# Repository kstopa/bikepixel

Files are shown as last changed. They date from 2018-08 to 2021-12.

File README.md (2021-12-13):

# Bike Pixels

Open Source Hardware project to build a set of highly customizable bycicle lights based on Arduino and Neo Pixel RGB matrixes. Currently all models can present different images in different colors with custom effects (blinking, bitting) and with adjustable brightness.

Check [Bike Pixel Official site](https://bikepixels.com) to the more details and recent news.

## Required software
All required applications to edit and design the different Bike Pixel models are open source. Bellow you can find all the tools that were used to design Bike Pixels:

* [Arduino IDE](https://www.arduino.cc/en/Main/Software): to write, biuld and upload the code to the Arduino board.
* [FreeCAD](https://www.freecadweb.org/wiki/Download): to design the cases.
* [KiCAD](http://kicad.org/download/): to design electronic schemas and the PCBs.
* [Fritzing](https://fritzing.org): only for circuit sketch documentation.

## Bike Pixel L (or rear)

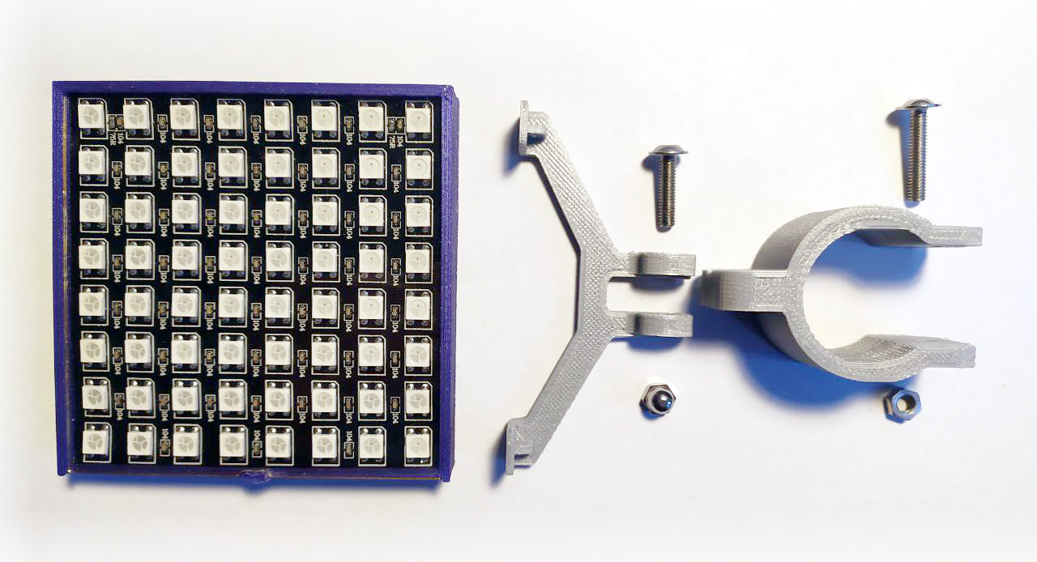
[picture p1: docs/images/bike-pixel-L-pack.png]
Bike Pixel L parts Bike Pixel L Parts


This model it is intended to be installed in the back part of the bike like the saddle or over bike structure. Main properties and parts:

* Preset 10 diferent icons
* Adjustable color and brightness
* 64 LEDs NeoPixel matrix
* 84 x 84 x 14 mm (3.3 x 3.3 x 0.55 in)

### Components

To build your own Bike Pixel L you should have all the elements listed on this bill of materials:

* 1 x Arduino Pro Mini or Nano;
* 1 x NeoPixel 8x8 matrix (80x80x2mm);
* 3 x 10 kΩ resistence;
* 1 x 470 Ω resistence;
* 2 x 22 kΩ resistor;
* 1 x 1000 uf/6.3V capacitator (recommended but optional);
* 3 x vertical touch switches;
* 1 x on\off botton (optional if your battery holder have one built-in);
* 1 x TP4056 module;
* 1 x 5V Step-up module;
* 1 x >2000 mAh LiPo battery;
* 1 x M3 30mm bolt;
* 1 x M3 20mm bolt; 
* 2 x M3 nuts;
* connection PCB;
* wires and soldering stuff;
* 3D printed case;
* 3D printed holder.

More details on each part are commented on following points. Links to different proviedars and prices can be found on this blog entry.

### Case

The case is divided in multiple parts designed to be 3D printed. Current designs include body and holder models.

#### Main body

The body is composed the main body and a cover. You can print them using PLA altought for the cover a 1 mm thick piece of plexi is recommended.

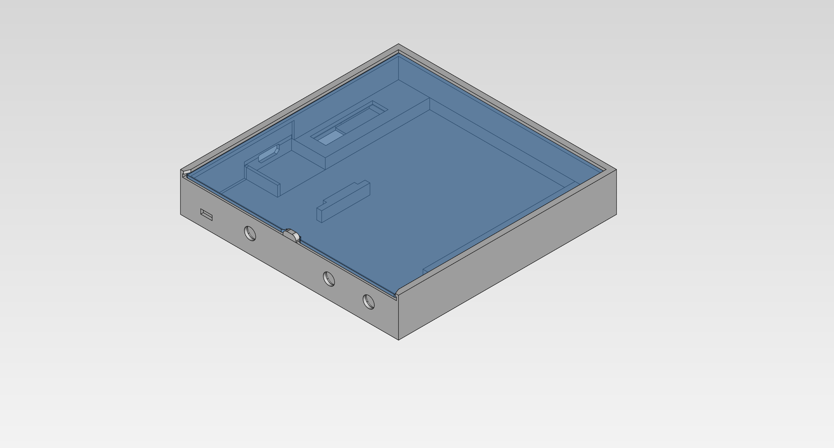
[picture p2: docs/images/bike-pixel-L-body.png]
Bike Pixel L body with cover Bike Pixel L body


You can get production files bellow.

| Part | Files |  
|---|---|
| Body | [sld](rear/case/body/case_bikepixels_rear.stl) |
| Cover| [sld](rear/case/cover/case_bikepixels_rear_cover.stl), [svg](rear/case/cover/case_bikepixels_rear_cover.svg), [pdf](rear/case/cover/case_bikepixels_rear_cover.pdf) |

#### Bike attachment 

Current holder design is divided into two pieces. An attachment and a hook. To mount them on a bycicle you will need 2 x M3 nuts and 2 x M3 bolts of 30 and 20mm in lenght.

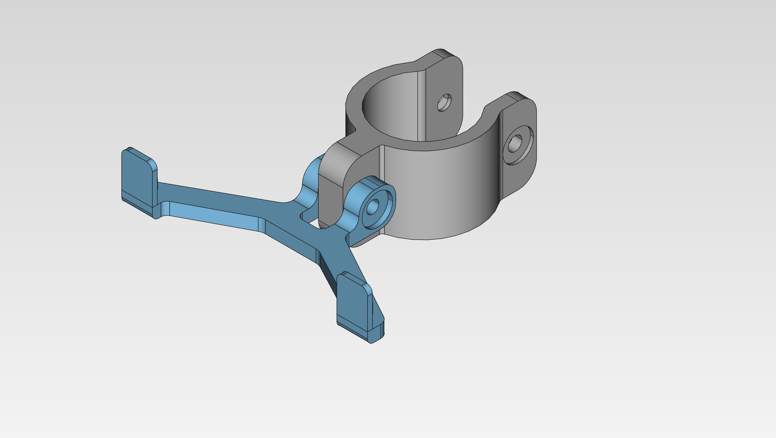
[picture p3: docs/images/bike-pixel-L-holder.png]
Bike Pixel L holder


You can get production files bellow.

|  Part | Files |
|---|---|
| Hook | [sld](rear/case/holder/holder_base_28mm-holder_hook.stl) |
| Attachment | [sld](rear/case/holder/holder_base_28mm-holder_attach.stl)  |

### Electronics

#### Main components

To build your L model you will need all the electronic parts listed bellow along with some additional requirements.

| Part | Comment |
|---|---|
| Arduino Nano or Pro Mini | Clone or original |
| USB C TP4056 charging module | More information on [this blog entry](https://bikepixels.com/2019/11/10/how-to-add-a-lipo-battery-in-our-arduino-projects/) |
| 5V Step-up module | Any module designed for LiPo batteries |
| NeoPixel 8x8 RGB matrix | Flexible 80x80x2mm model |
| >2000 LiPo battery | Max. 4 mm thicknes |

#### Conexions PCB

The PCB encapsulates the switches and manage connections between the Arduino board, the step-up module and the RGB matrix. All the design have been created with KiCAD. All the source files including schematinc, netlist and PCB board are availble [here](./rear/electronics/bikepixel rear/).

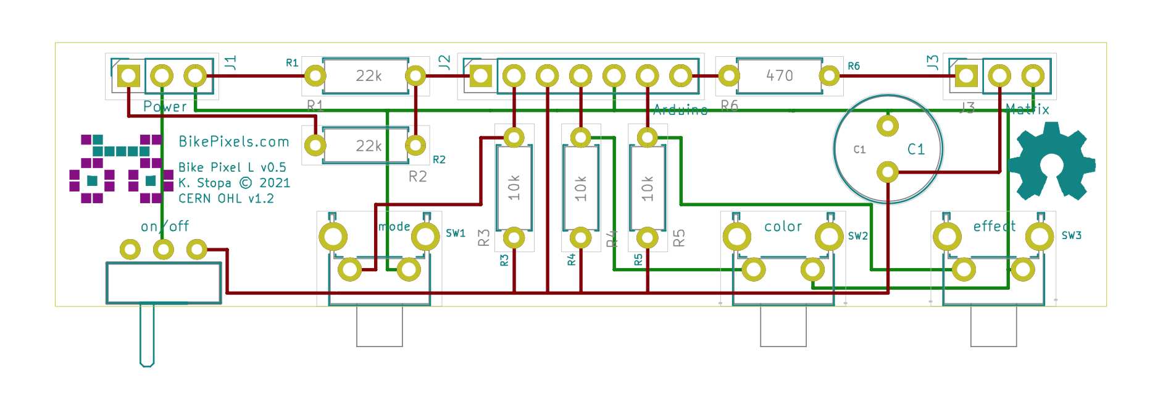
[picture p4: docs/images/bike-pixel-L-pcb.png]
Bike Pixel L PCB


Production files are available in different formats and are linked bellow:

|                         Format                           |
|----------------------------------------------------------|
| [gerber](rear/electronics/production files/gerber)       |
| [pdf](rear/electronics/production files/pdf)             |
| [svg](rear/electronics/production files/svg)             |

#### Assambley

To connect evrything together please follow schema bellow. After soldering everthing you can proceed to upload the code to Arduino.

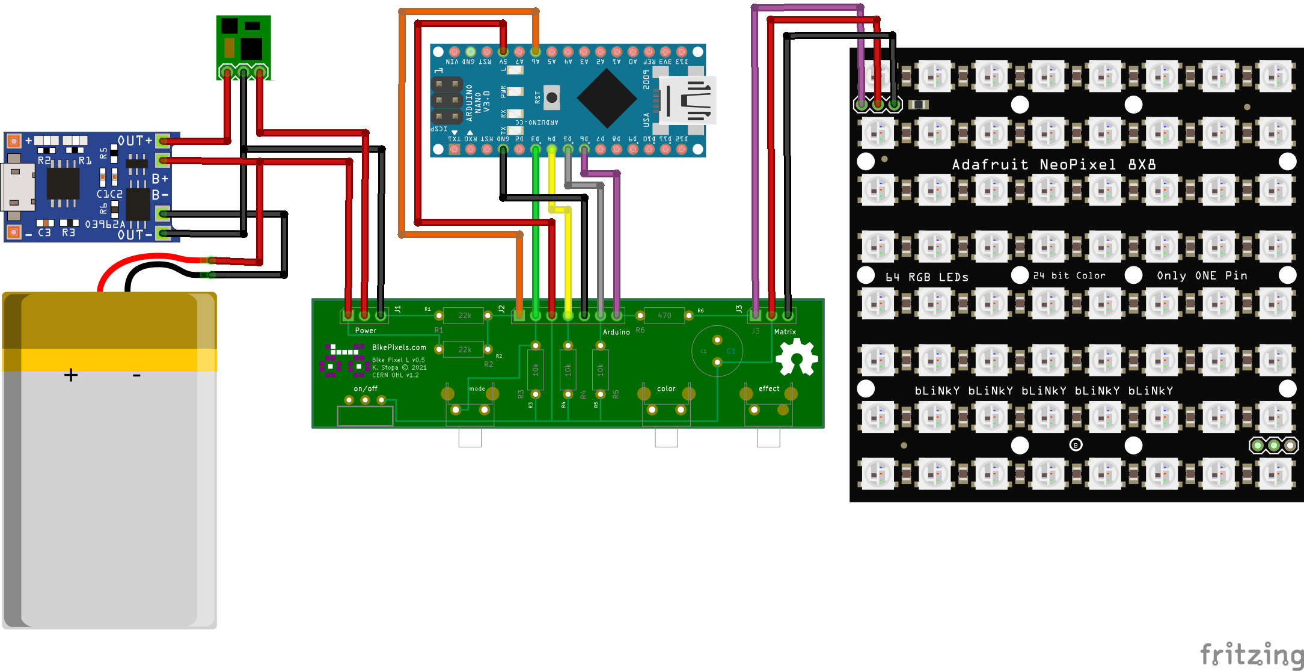
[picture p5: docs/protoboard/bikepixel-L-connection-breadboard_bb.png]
Bike Pixel L connection BikePixel PCB conection


## Code 

To compile the BikePixel [code for Arduino](./rear/src/bikepixel_sketch.ino), you'll need some extra libraries:

* [Adafruit GFX](https://github.com/adafruit/Adafruit-GFX-Library)
* [Adafruit NeoPixel](https://github.com/adafruit/Adafruit_NeoPixel)
* [Adafruit NeoMatrix](https://github.com/adafruit/Adafruit_NeoMatrix)

Note that you can install these libraries directly from Arduino Studio (Sketch menu, > Include Library > Manage Libraries) or by placing it after download into the Arduino Library folder (usally in your home).

## Certification

Bike Pixel is certified by the Open Source Hardware Association ([OSHWA](https://en.wikipedia.org/wiki/Open_Source_Hardware_Association)). 
OSWHA is a non-profit organization that advocates for open-source hardware focusing on promotion, education and comertialization of open 
products. OSHWA also manages certification program for open-source hardware that indicate that given product meet standard criteria for 
open-source compliance. Current Bike Pixel version has certificate number [PL000007](https://certification.oshwa.org/pl000007.html).

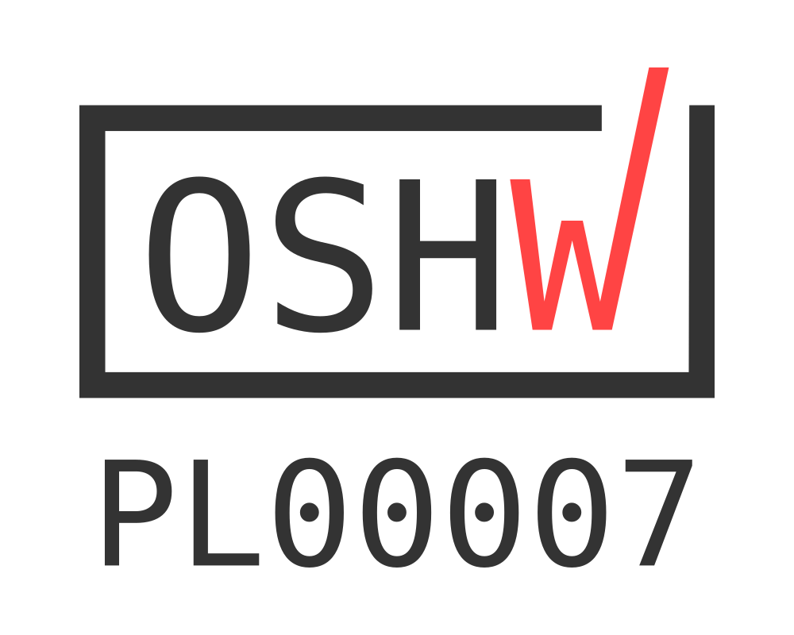
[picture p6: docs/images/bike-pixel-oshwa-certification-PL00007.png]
Bike Pixels OSHWA certificate PL000007 Bike Pixels OSHWA certificate


## License

As the project is compond by software, hardware and documentation each of these parts are licensed under the terms of specific license.

### Software License

Copyright © 2021 by BikePixels.com and contributors:

* Krzysztof Stopa ([kstopa](https://github.com/kstopa/)).

Bike Pixels contains free software: you can redistribute it and/or modify it under the terms of the GNU General Public License as published by the Free Software Foundation, either version 3 of the License, or any later version.

Bike Pixels is distributed in the hope that it will be useful, but WITHOUT ANY WARRANTY; without even the implied warranty of MERCHANTABILITY or FITNESS FOR A PARTICULAR PURPOSE. See the GNU Lesser General Public License for more details.

You should have received a copy of the GNU Lesser General Public License along with CAMS tools. If not, see http://www.gnu.org/licenses/.

### Hardware License

Copyright © 2021 by BikePixels.com and contributors:

* Krzysztof Stopa ([kstopa](https://github.com/kstopa/)).

Hardware elements is licensed under the CERN OHL v. 1.2.

You may redistribute and modify this documentation under the terms of the CERN OHL v.1.2. (http://ohwr.org/cernohl). This documentation is distributed WITHOUT ANY EXPRESS OR IMPLIED WARRANTY, INCLUDING OF MERCHANTABILITY, SATISFACTORY QUALITY AND FITNESS FOR A PARTICULAR PURPOSE. Please see the CERN OHL v.1.2 for applicable conditions.

### Documentation and images License

Copyright © 2021 by BikePixels.com and contributors:

* Krzysztof Stopa ([kstopa](https://github.com/kstopa/)).

Documentation and image files are distributed under the Attribution-ShareAlike 4.0 International (CC BY-SA 4.0) lisence. The full text of the license can be found at the [CC BY-SA 4.0 page](https://creativecommons.org/licenses/by-sa/4.0/legalcode).

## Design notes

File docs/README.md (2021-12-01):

# Content

## Custom parts

Contains all custom parts used on KiCad and Fritzing used to design Bike Pixels Front and
Rear cirquits and PCBs.

## Protoboard

Contains proto board simple design used for design and debugging.

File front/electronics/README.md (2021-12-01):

This folder contains:
 * custom components: i.e. parts and graphinc elements that compuds the PCB design.
 * production files: to be send in `gerber` and `svg` formats that  can be directly send to a PCB manufacturer.

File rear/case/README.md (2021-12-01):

# Content

This folder conaint all the needed files to print a Bike Pixel L (or rear) case

* body: FreeCAD file and production stl with the case main body.
* cover: FreeCAD file and production stl, pdf and svg files with the body cover (as can be printed or cut on plexy).
* holder: FreeCAD file and production of a holder to attach the body to the bike for different sizes. Includes production files for the bike attachment and a hook parts.

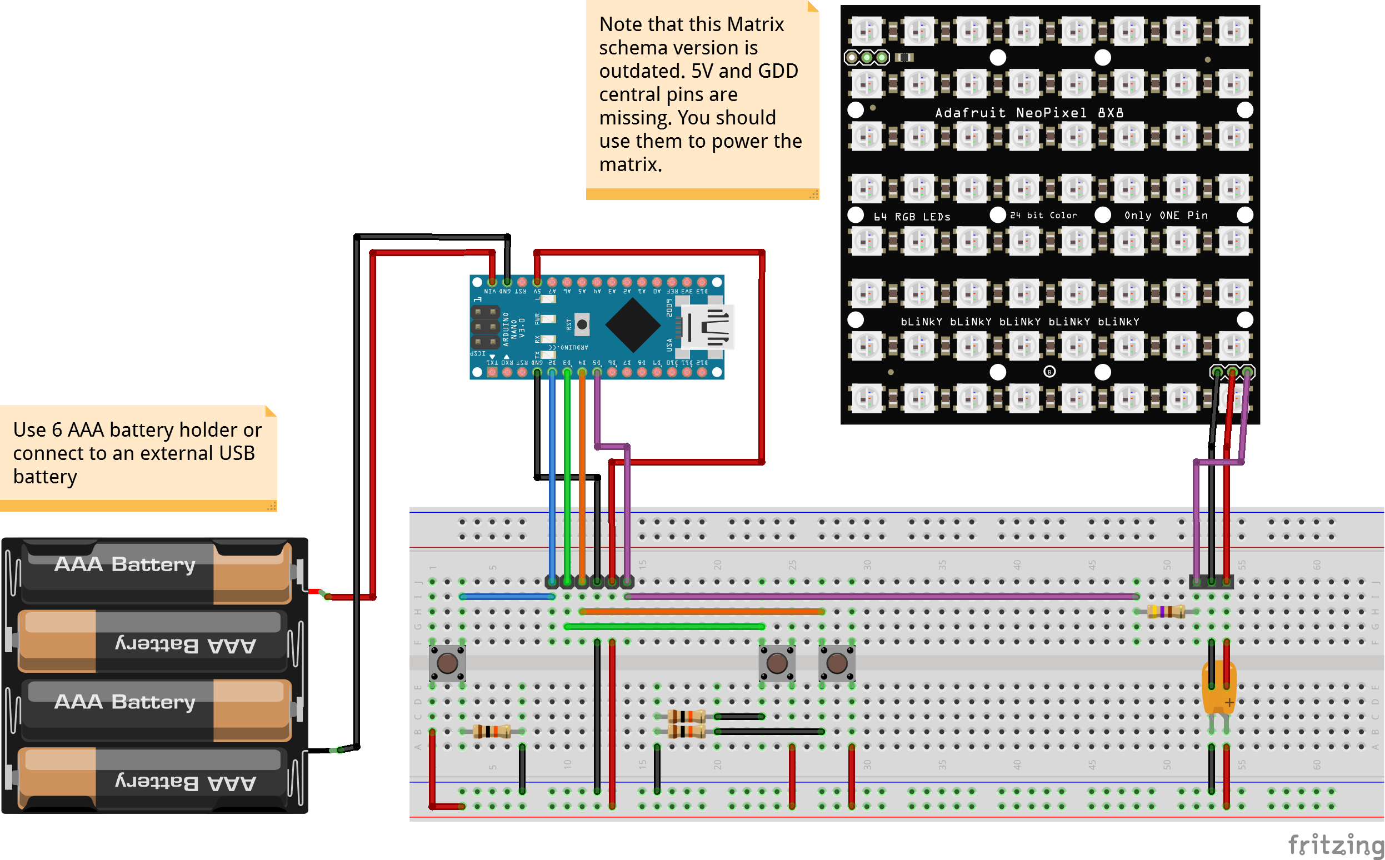
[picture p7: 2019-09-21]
rear/electronics/sketch protoboard.png

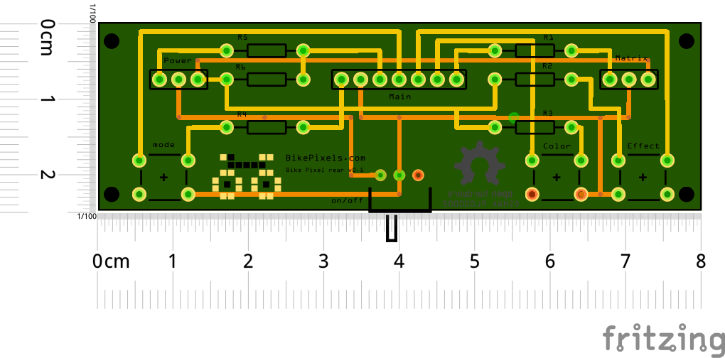
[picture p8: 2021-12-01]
rear/electronics/sketch pcb.png

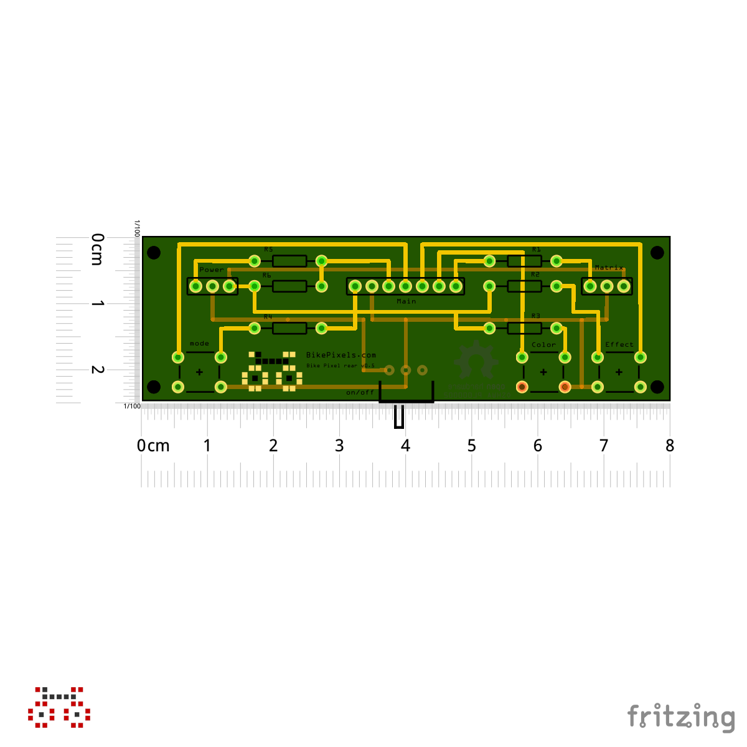
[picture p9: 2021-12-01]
rear/electronics/sketch pcb_pcb.png

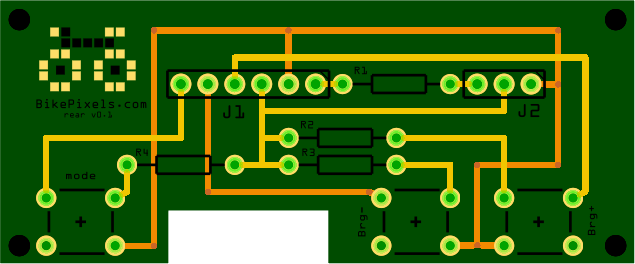
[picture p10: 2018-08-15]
docs/protoboard/sketch pcb.png

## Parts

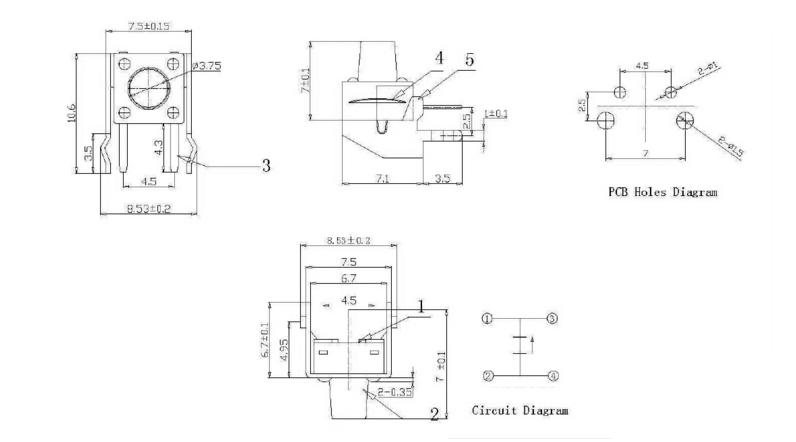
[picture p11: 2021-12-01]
front/electronics/custom components/pushbutton_vertical_sketch.jpg

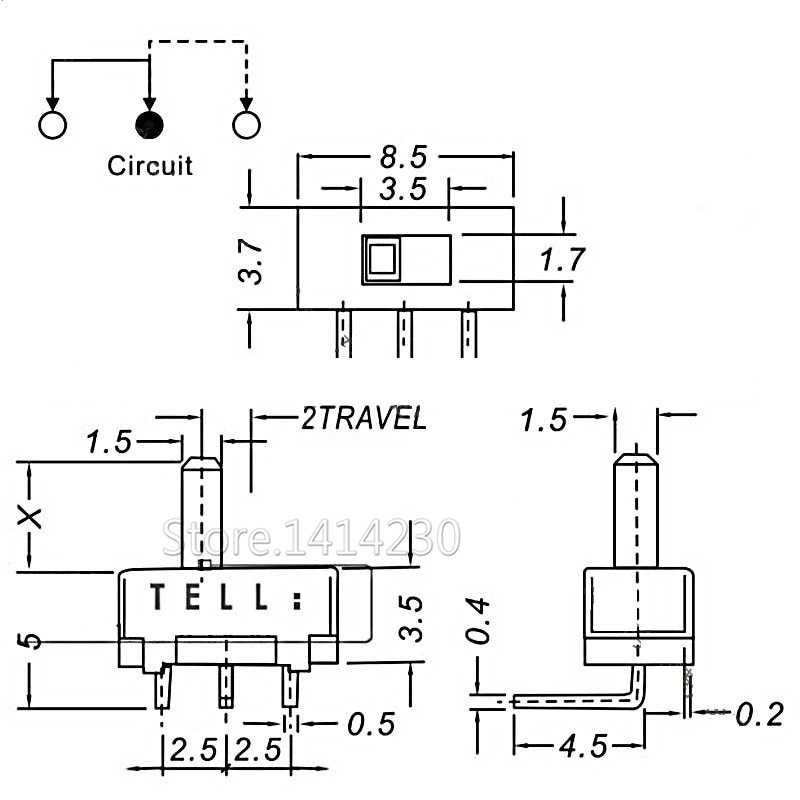
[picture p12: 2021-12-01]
front/electronics/custom components/fritzing_onoff_slide_switch on-off-mini-SS12D00-SS12D03G5-3pin.jpg

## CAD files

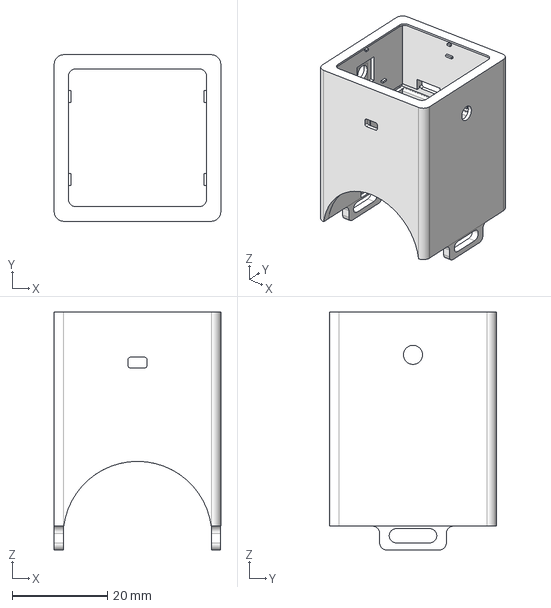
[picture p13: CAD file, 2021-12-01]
front/case/bikepixel_front_45.FCStd
35.0 x 35.0 x 50.0 mm

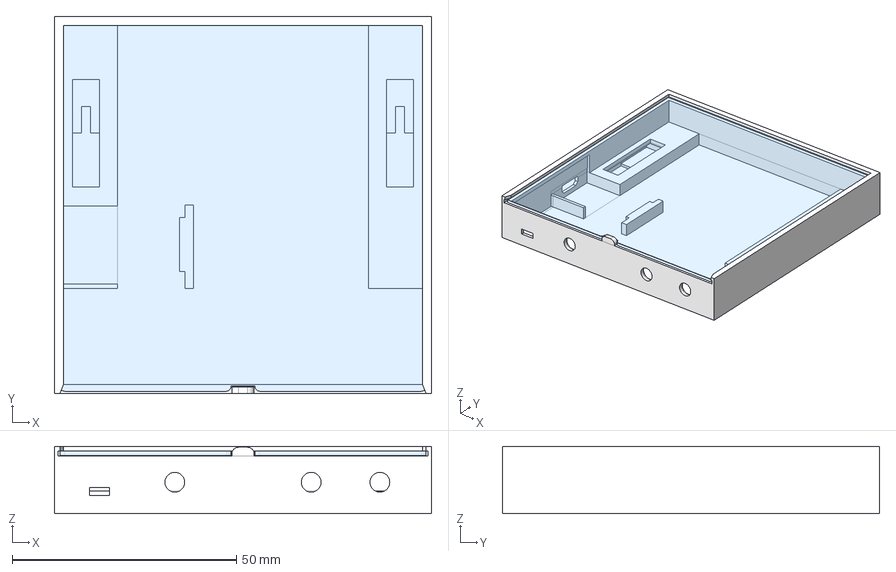
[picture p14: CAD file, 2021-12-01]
rear/case/body/case_bikepixels_rear.FCStd
84.0 x 84.0 x 15.0 mm
Case body
Case cover

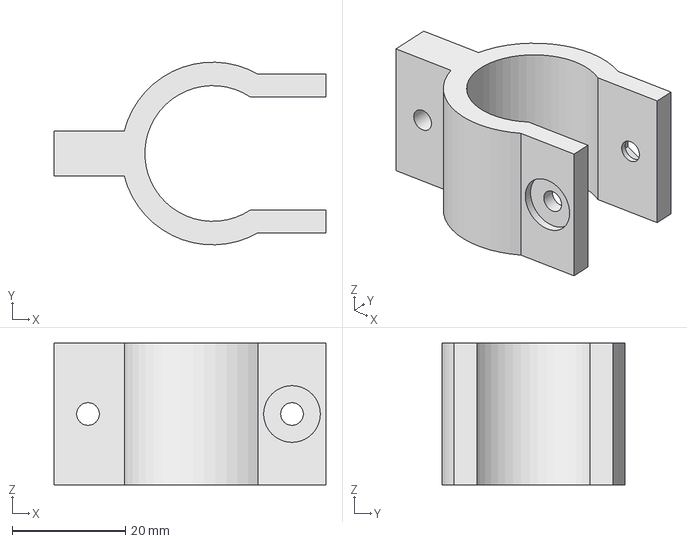
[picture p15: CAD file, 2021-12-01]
rear/case/holder/holder_base_24mm.FCStd
48.0 x 32.2 x 25.0 mm

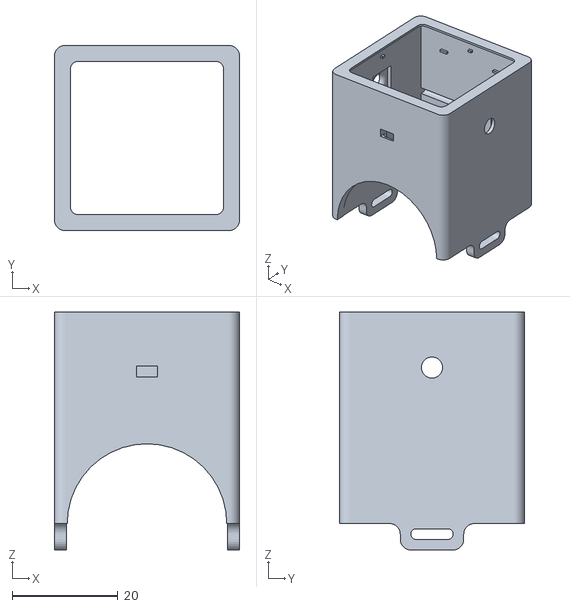
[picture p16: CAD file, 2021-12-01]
front/case/bike_pixel_front_v0.stl
35.0 x 35.0 x 45.0

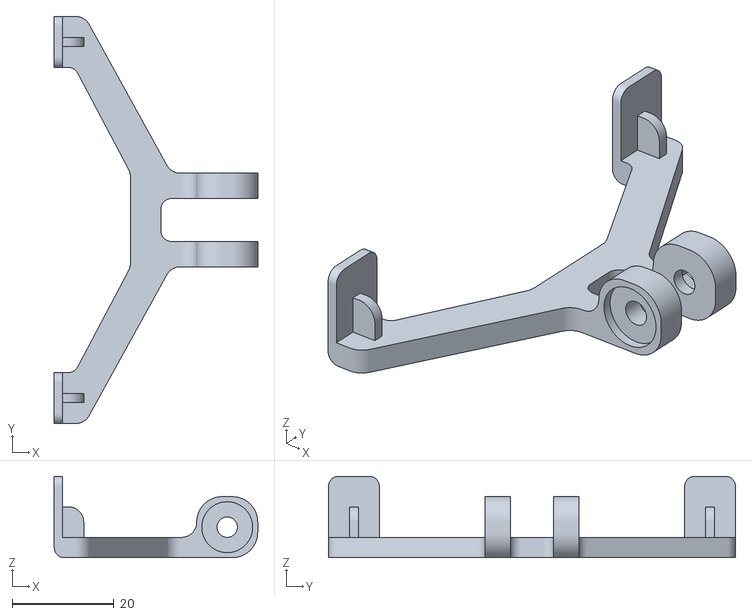
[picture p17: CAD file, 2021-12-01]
rear/case/holder/holder_base_28mm-holder_hook.stl
40.0 x 80.0 x 16.0

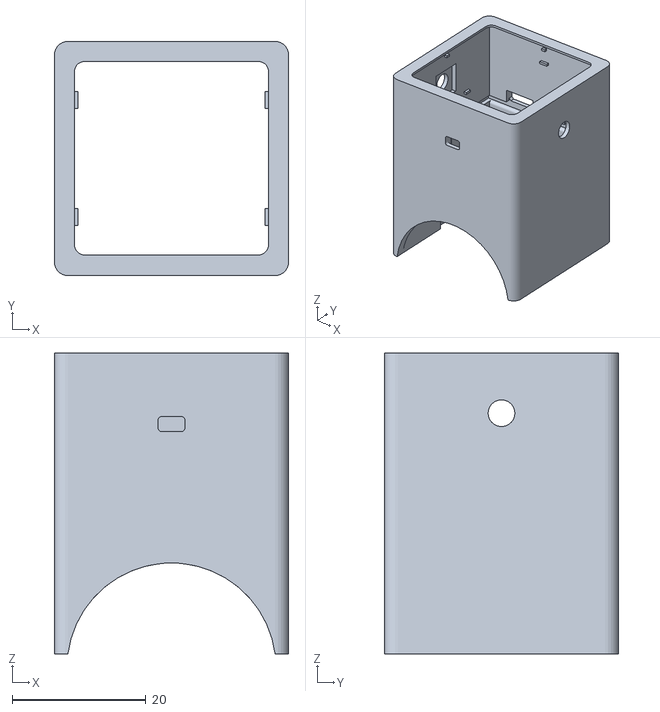
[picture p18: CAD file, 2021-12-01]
front/case/bike_pixels_front.stl
35.0 x 35.0 x 45.0

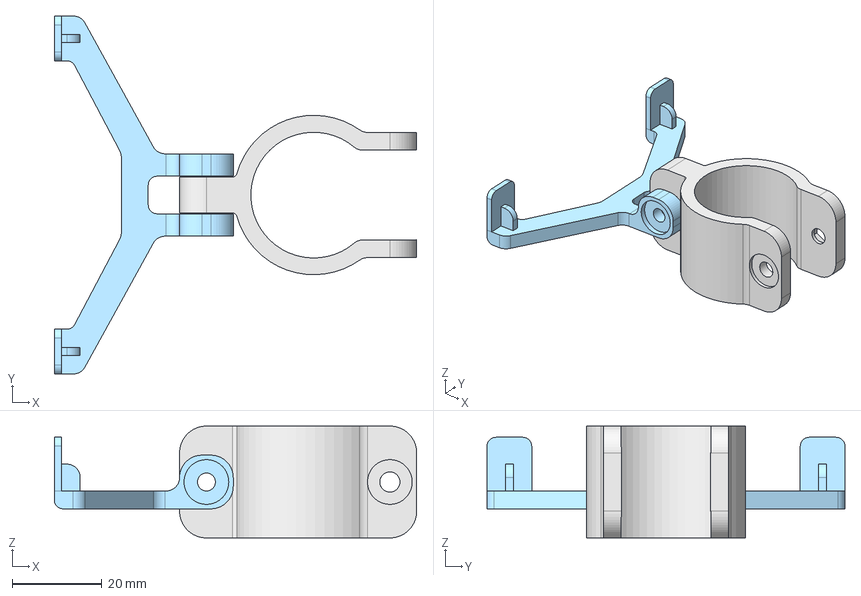
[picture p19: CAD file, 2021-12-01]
rear/case/holder/holder_base_28mm.FCStd
81.0 x 80.0 x 25.0 mm
holder_attach
holder_hook

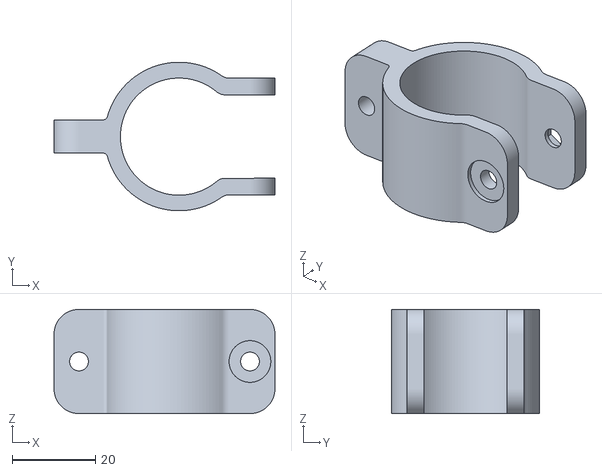
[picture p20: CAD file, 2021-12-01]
rear/case/holder/holder_base_28mm-holder_attach.stl
53.0 x 35.6 x 25.0

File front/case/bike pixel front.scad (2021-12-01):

module roundedcube(size = [1, 1, 1], center = false, radius = 0.5, apply_to = "all") {
	// If single value, convert to [x, y, z] vector
	size = (size[0] == undef) ? [size, size, size] : size;

	translate_min = radius;
	translate_xmax = size[0] - radius;
	translate_ymax = size[1] - radius;
	translate_zmax = size[2] - radius;

	diameter = radius * 2;

	module build_point(type = "sphere", rotate = [0, 0, 0]) {
		if (type == "sphere") {
			sphere(r = radius);
		} else if (type == "cylinder") {
			rotate(a = rotate)
			cylinder(h = diameter, r = radius, center = true);
		}
	}

	obj_translate = (center == false) ?
		[0, 0, 0] : [
			-(size[0] / 2),
			-(size[1] / 2),
			-(size[2] / 2)
		];

	translate(v = obj_translate) {
		hull() {
			for (translate_x = [translate_min, translate_xmax]) {
				x_at = (translate_x == translate_min) ? "min" : "max";
				for (translate_y = [translate_min, translate_ymax]) {
					y_at = (translate_y == translate_min) ? "min" : "max";
					for (translate_z = [translate_min, translate_zmax]) {
						z_at = (translate_z == translate_min) ? "min" : "max";

						translate(v = [translate_x, translate_y, translate_z])
						if (
							(apply_to == "all") ||
							(apply_to == "xmin" && x_at == "min") || (apply_to == "xmax" && x_at == "max") ||
							(apply_to == "ymin" && y_at == "min") || (apply_to == "ymax" && y_at == "max") ||
							(apply_to == "zmin" && z_at == "min") || (apply_to == "zmax" && z_at == "max")
						) {
							build_point("sphere");
						} else {
							rotate = 
								(apply_to == "xmin" || apply_to == "xmax" || apply_to == "x") ? [0, 90, 0] : (
								(apply_to == "ymin" || apply_to == "ymax" || apply_to == "y") ? [90, 90, 0] :
								[0, 0, 0]
							);
							build_point("cylinder", rotate);
						}
					}
				}
			}
		}
	}
}



width=44;
length=44;
height=44;

diference() {
    
    roundedcube([width, length, height], true, 4);
    cube([width/2, lenght/2, height-4], true);
}

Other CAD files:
rear/case/cover/case_bikepixels_rear_cover.FCStd
front/case/bike pixel front.FCStd
front/case/bike_pixel_front.stl
rear/case/body/case_bikepixels_rear.stl
rear/case/cover/case_bikepixels_rear_cover.stl

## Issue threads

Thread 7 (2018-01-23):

Update NeoMatrix Fritzing component

kstopa, 2018-01-23:
Add missing 5V and GDD connectors to NeoMatrix component (see docs/Adafruit NeoPixel NeoMatrix 8x8 component.fzpz)

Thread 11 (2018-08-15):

Update case

kstopa, 2018-08-15:
Solve issues with case from first iteration (should be 2 mm higher, 1.6M for screw holes, 2 mm min thin of the bottom wall, consider to add final usb connector)

Closed 2018-09-09.

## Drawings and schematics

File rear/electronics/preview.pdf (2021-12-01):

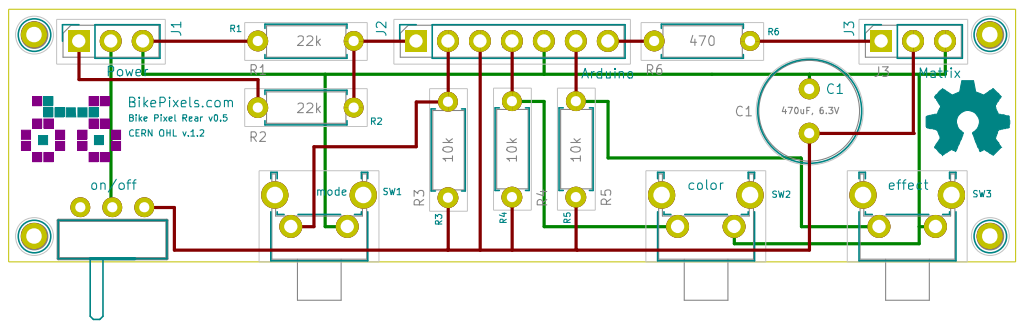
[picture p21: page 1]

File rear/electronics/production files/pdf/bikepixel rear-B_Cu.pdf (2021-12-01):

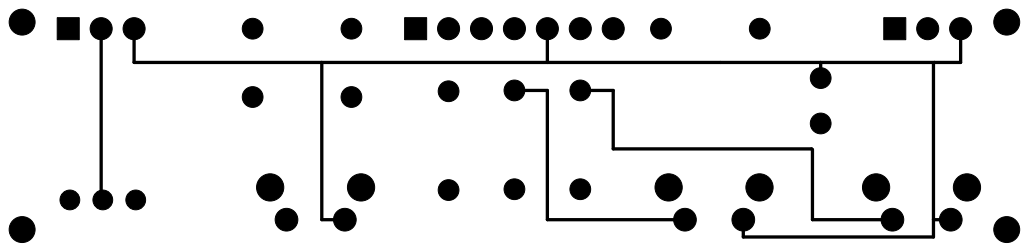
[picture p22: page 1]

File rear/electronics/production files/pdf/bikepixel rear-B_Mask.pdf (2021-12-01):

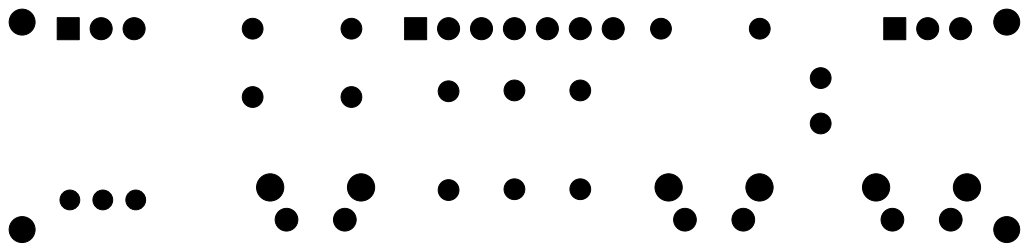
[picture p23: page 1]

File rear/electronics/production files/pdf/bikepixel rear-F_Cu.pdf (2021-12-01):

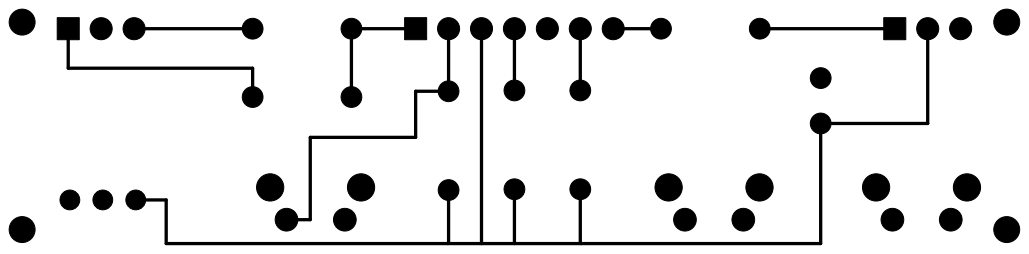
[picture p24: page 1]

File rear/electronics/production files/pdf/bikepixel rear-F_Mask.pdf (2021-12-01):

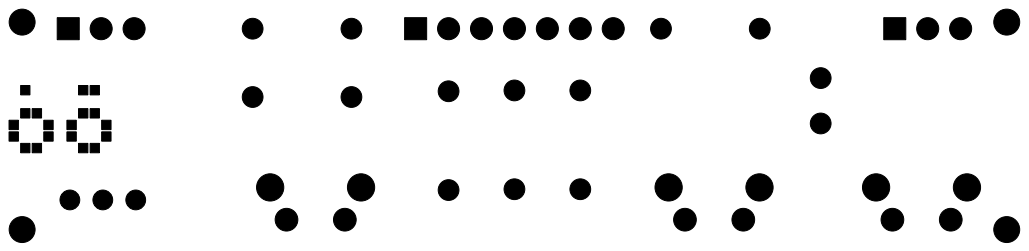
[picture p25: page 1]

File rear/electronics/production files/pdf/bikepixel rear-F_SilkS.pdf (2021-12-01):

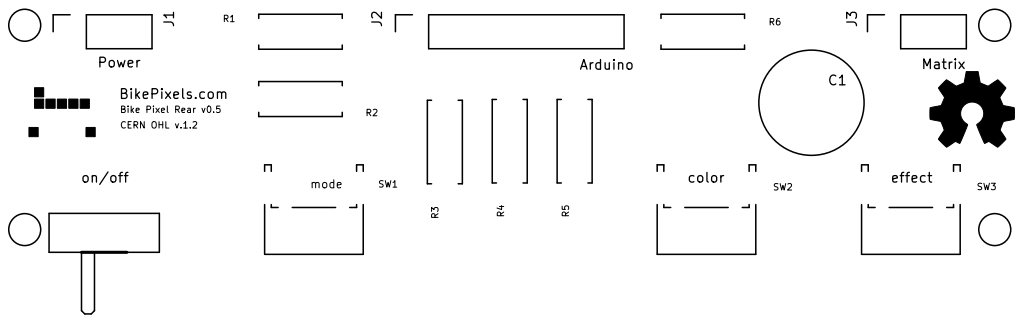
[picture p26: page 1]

CERN OHL v.1.2 Bike Pixel Rear v0.5 BikePixels.com

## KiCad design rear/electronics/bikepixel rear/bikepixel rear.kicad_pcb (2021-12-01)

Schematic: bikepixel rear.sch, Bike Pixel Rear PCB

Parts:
C1: 470uF, 6.3V; C_Radial_D8.0mm_H7.0mm_P3.50mm
J1: Power; PinSocket_1x03_P2.54mm_Vertical
J2: Arduino; PinSocket_1x07_P2.54mm_Vertical
J3: Matrix; PinSocket_1x03_P2.54mm_Vertical
R1, R2: 22k; R_Axial_DIN0207_L6.3mm_D2.5mm_P7.62mm_Horizontal
R3, R4, R5: 10k; R_Axial_DIN0207_L6.3mm_D2.5mm_P7.62mm_Horizontal
R6: 470; R_Axial_DIN0207_L6.3mm_D2.5mm_P7.62mm_Horizontal
SW0: on/off; SW-SPDT-SS12D00-Angled
SW1: mode; SW_Tactile_SPST_Angled_PTS645Vx58-2LFS
SW2: color; SW_Tactile_SPST_Angled_PTS645Vx58-2LFS
SW3: effect; SW_Tactile_SPST_Angled_PTS645Vx58-2LFS

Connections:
+5V: C1.2, J2.3, J3.2, R3.1, R4.1, R5.1, SW0.3
GND: C1.1, J1.3, J2.5, J3.3, R1.1, SW1.1, SW2.1, SW3.1
unnamed: J1.1, R2.1
unnamed: J1.2, SW0.2
unnamed: J2.1, R1.2, R2.2
unnamed: J2.2, R3.2, SW1.2
unnamed: J2.4, R4.2, SW2.2
unnamed: J2.6, R5.2, SW3.2
unnamed: J2.7, R6.1
unnamed: J3.1, R6.2

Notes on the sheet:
Note that in the matrix specs a 1000 uF capacitator is recommended but due to size restrctions a smaller one is used.

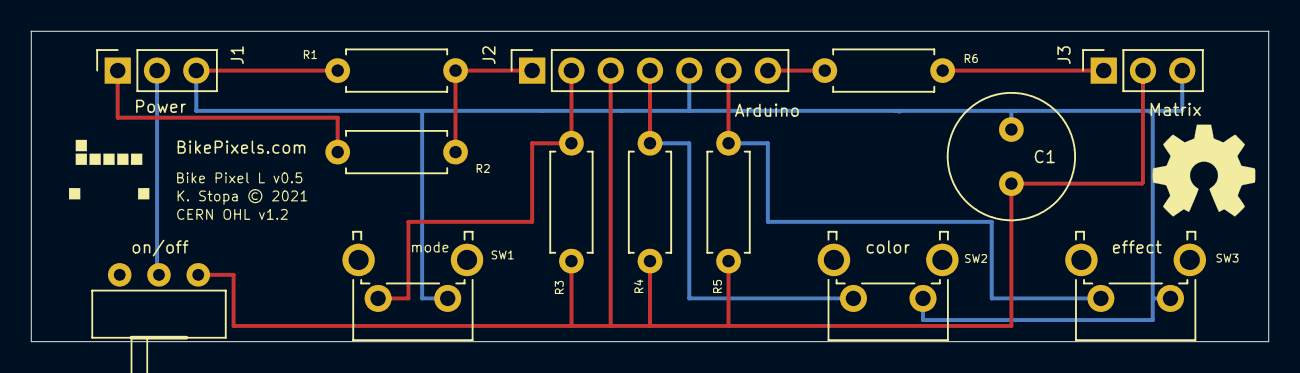
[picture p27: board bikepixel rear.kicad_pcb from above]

Board: 2 copper layers, 80.0 x 20.1 mm, 17 parts (0 on the bottom side), 10 nets.

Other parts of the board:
CERN OHL v1.2: Bike Pixel L v0.5; bikepixels_logo_black_part_silk_05mm
K. Stopa © 2021: BikePixels.com; bikepixels_logo_red_part_solder_05mm
OSHW: OSHW; OSHW-Symbol_6.7x6mm_SilkScreen

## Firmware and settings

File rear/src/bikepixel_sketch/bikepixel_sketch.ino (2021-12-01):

#include <Adafruit_GFX.h>
#include <Adafruit_NeoPixel.h>
#include <Adafruit_NeoMatrix.h>

#define DEBUG                   true

// PINs definitions
#define PIN_BATT_STATUS         A0
#define PIN_MODE_BTN            3
#define PIN_BRIGHT_BTN          4
#define PIN_COLOR_BTN           5
#define PIN_NEO_PIXEL           6


#define VMIN      3.6
/*=========================================================================
APPLICATION SETTINGS
                          
MATRIX DECLARATION        Parameter 1 = width of NeoPixel matrix
                          Parameter 2 = height of matrix
                          Parameter 3 = pin number (most are valid)
                          Parameter 4 = matrix layout flags, add together as needed:
NEO_MATRIX_TOP,
NEO_MATRIX_BOTTOM,
NEO_MATRIX_LEFT,
NEO_MATRIX_RIGHT          Position of the FIRST LED in the matrix; pick two, e.g.
                          NEO_MATRIX_TOP + NEO_MATRIX_LEFT for the top-left corner.
                          NEO_MATRIX_ROWS, NEO_MATRIX_COLUMNS: LEDs are arranged in horizontal
                          rows or in vertical columns, respectively; pick one or the other.
NEO_MATRIX_PROGRESSIVE,
NEO_MATRIX_ZIGZAG         all rows/columns proceed in the same order, 
                          or alternate lines reverse direction; pick one.

                          See example below for these values in action.

Parameter 5 = pixel type flags, add together as needed:
                          
NEO_KHZ800                800 KHz bitstream (most NeoPixel products w/WS2812 LEDs)
NEO_KHZ400                400 KHz (classic 'v1' (not v2) FLORA pixels, WS2811 drivers)
NEO_GRB                   Pixels are wired for GRB bitstream (most NeoPixel products)
NEO_RGB                   Pixels are wired for RGB bitstream (v1 FLORA pixels, not v2)
-----------------------------------------------------------------------*/
 
// NeoPixel 8x8 Matrix.  In this application we'd like to use it 
// with the back text positioned along the bottom edge.
// When held that way, the first pixel is at the top left, and 
// lines are arranged in columns, zigzag order.  The 8x8 matrix uses
// 800 KHz (v2) pixels that expect GRB color data.
Adafruit_NeoMatrix matrix = Adafruit_NeoMatrix(8, 8, PIN_NEO_PIXEL,
  NEO_MATRIX_TOP     + NEO_MATRIX_LEFT +
  NEO_MATRIX_COLUMNS + NEO_MATRIX_ZIGZAG,
  NEO_GRB            + NEO_KHZ800);
/*=========================================================================*/



/** modes:
 *  0 - Bike Pixel logo welcome 
 *  1 - full red square 
 *  2 - full red square blink effect (that changes in intensity)
 *  3 - red circle 
 *  4 - red circle blink effect
 *  5 - changing red squares 
 *  6 - Skull
 *  7 - PacMan
 *  8 - Invader
 *  9 - Christmas tree
 */
int mode = 0; 
int vStep = 0;        // Vertical step for big images
int vMove = 1;        // move right (1) or left (-1)
int brightMin = 5;    // Minimum bright
int brightState = 240; // Current bright status (for effects)
int brightStep = 15;
int brightMax = 255;

uint32_t red = matrix.Color(255, 20, 20);
uint32_t orange = matrix.Color(253, 138, 59);
uint32_t yellow = matrix.Color(249, 233, 63);
uint32_t green = matrix.Color(161, 237, 45);
uint32_t tree = matrix.Color(26, 174, 67);
uint32_t blue = matrix.Color(20, 85, 75);
uint32_t marine = matrix.Color(11, 81, 190);
uint32_t violet = matrix.Color(210, 47, 210);
uint32_t purple = matrix.Color(120, 20, 150); 
uint32_t white = matrix.Color(200, 200, 200); 
int colorIndex = 0;
int effect = 0; 
// Numer of updates since last button pressed.
int ticks = 0;

// 
 uint32_t colors[] = {
  red,
  matrix.Color(220, 125, 220),  // Pink
  matrix.Color(130, 0, 160),  // Violet
  matrix.Color(40, 120, 220),  // Blue
  matrix.Color(40, 140, 40),  // Green
  matrix.Color(255, 255, 0),  // Yellow
  matrix.Color(200, 200, 200),  // White
 };
// Battery voltage

float vBat = 4.2;
 
// Welcome Bike Pixels moveing logo
const int BP_ROWS = 6;
const int BP_COLS = 40; 
const uint32_t welcome[BP_ROWS][BP_COLS] = {
  {0,   0,   0,   0, 0,      0, 0,      0,      0,      0, 0,     0,     0,     0, 0, 0,    0,    0,    0, 0,    0, 0,      0,      0,      0, 0,      0,      0,      0, 0,      0,      0,   red, white, 0,     0,     0,      red,   red, 0},                    
  {red, red, red, 0, orange, 0, yellow, 0,      0,      0, 0,     0,     0,     0, 0, tree, tree, tree, 0, blue, 0, 0,      0,      0,      0, 0,      0,      0,      0, purple, 0,      0,   0,   white, white, white, white,  white, 0,   0},
  {red, 0,   red, 0, 0     , 0, yellow, 0,      0,      0, 0,     green, green, 0, 0, tree, 0,    tree, 0, 0,    0, 0,      0,      0,      0, 0,      violet, violet, 0, purple, 0,      0,   red, red,   0,     0,     0,      red,   red, 0},
  {red, red, red, 0, orange, 0, yellow, 0,      yellow, 0, green, green, green, 0, 0, tree, tree, tree, 0, blue, 0, marine, 0,      marine, 0, violet, violet, violet, 0, purple, 0,      red, 0,   0,     red,   0,     red,    0,     0,   red},
  {red, 0,   red, 0, orange, 0, yellow, yellow, 0,      0, green, 0,     0,     0, 0, tree, 0,    0,    0, blue, 0, 0,      marine, 0,      0, violet, 0,      0,      0, purple, 0,      red, 0,   0,     red,   0,     red,    0,     0,   red},
  {red, red, red, 0, orange, 0, yellow, 0     , yellow, 0, 0    , green, green, 0, 0, tree, 0,    0,    0, blue, 0, marine, 0,      marine, 0, 0,      violet, violet, 0, purple, purple, 0,   red, red,   0,     0,     0,      red,   red, 0}   
};

void setup(void)
{
  // Matrix initialization
  matrix.begin();
  matrix.setBrightness(brightState);
  matrix.fillScreen(0);
  matrix.show(); // This sends the updated pixel colors to the hardware.
  drawMode(mode, colors[colorIndex]);
  // PINs setup
  pinMode(PIN_MODE_BTN, INPUT);
  pinMode(PIN_BRIGHT_BTN, INPUT);
  pinMode(PIN_COLOR_BTN, INPUT);
  if (DEBUG) {
    Serial.begin(9600);
  }
}

bool checkModeButton(int pin) {
  int buttonState = 0;
  if (ticks < 5) return false;  // Avoid to read twice same button press
  buttonState = digitalRead(pin);
  // Check if the pushbutton is pressed. If it is, the buttonState is LOW as they are pulled up
  if ((buttonState == LOW) && (mode <= 9)) {
    mode++;
    ticks = 0;
    return true;
  } else if ((buttonState == LOW) && (mode >= 10)){
    // turn LED off:
    mode = 0;
    ticks = 0;
    return true;
  } else {
    // No changes
    return false;
  }
}

bool checkColorButton(int pin) {
  if (ticks < 5) return false;  // Avoid to read twice same button press
  int buttonState = 0;
  buttonState = digitalRead(pin);
  if (buttonState == LOW){ 
    if (colorIndex + 1 < sizeof(colors)/4) {
      colorIndex++;
    } else {
      colorIndex = 0;
    }
    ticks = 0;
    return true;
  }
  return false;
}

bool checkBrightButton(int pin) {
  int buttonState = 0;
  if (ticks < 5) return false;  // Avoid to read twice same button press
  buttonState = digitalRead(pin);
  if (buttonState == LOW) {
    brightMax += 32;
    if (brightMax > 255) {
      brightMax = 31;
      brightStep = 2;
    } else {
      if (brightMax < 20) {
        brightStep = 2;
      } else if (brightMax < 50) {
        brightStep = 3;
      } else if (brightMax < 100) {
        brightStep = 7;
      } else {
        brightStep = 15;
      }
    }
    if (DEBUG) {
      Serial.println("B Max");
      Serial.println(brightMax);
      Serial.println("B Step");
      Serial.println(brightStep);
    }
    ticks = 0;
    return true;
  } else {
    return false;
  }
}

float checkBatteryStatus() {
  vBat = float(analogRead(PIN_BATT_STATUS));
  vBat = 5.0*vBat/1024.0;      // Convert to voltage note that vcc (5V) is divided by 2
  if (DEBUG) {
    Serial.println("Vcc");
    Serial.println(vBat);
  }
  return vBat;
}

void updateBrightEffect() {
  brightState += brightStep;
  if (brightState >= brightMax) {
    brightState = brightMax;
    brightStep = -1 * brightStep;
  } else if (brightState <= abs(brightMin)) {
    brightState = 5;
    brightStep =  abs(brightStep);
  }
  matrix.setBrightness(brightState);
  if (DEBUG) {
    Serial.println(brightState);
  }
  matrix.show();
}

void drawPercent(uint32_t c, int cur_val, float max_value, int row) {
  short indicator_length = 0;
  indicator_length = (short) 8.0 * ((cur_val + 1) * 1.0/ max_value);
  if (indicator_length > 0) {
    matrix.drawFastHLine(0, row, indicator_length, c);
  }
}

/**
 * Draw welcome message with along with the brightness setup.
 */
void drawWelcome(int step) {
  step = ceil(step / 1);
  if (step < 0) {
    vMove = 1;
    step = 0;
  }
  matrix.fillScreen(0);
  for (int nr = 0; nr < BP_ROWS; nr++) {
    for (int nc = 0 + step; nc < max(8 + step, BP_COLS); nc++) {
      matrix.drawPixel(nc - step, nr, welcome[nr][nc]);  
    }
  }

  if (step > BP_COLS - 8) {
    vMove = -1;
    delay(500);
  }

  drawPercent(white, checkBatteryStatus()-VMIN, 4.2-VMIN, 6);
  drawPercent(red, brightMax, 255.0, 7);
  
}

void drawDot(uint32_t c) {  
  matrix.fillCircle(4, 4, 3, c);
}

void drawInvader(uint32_t c) {
  matrix.drawPixel(1, 0, c);        
  matrix.drawPixel(6, 0, c);
  matrix.drawFastHLine(2, 1, 4, c);
  matrix.drawFastHLine(1, 2, 6, c);
  matrix.drawFastHLine(0, 3, 2, c);
  matrix.drawFastHLine(3, 3, 2, c);
  matrix.drawFastHLine(6, 3, 2, c);
  matrix.drawFastHLine(1, 4, 6, c);
  matrix.drawPixel(1, 5, c);        
  matrix.drawPixel(6, 5, c);
  matrix.drawPixel(2, 6, c);        
  matrix.drawPixel(5, 6, c);
}

void drawChristmasTree(uint32_t c_tree, uint32_t c_dec) {
  matrix.drawFastHLine(3, 0, 2, matrix.Color(255, 255, 0)); // Yellow star
  // Tree
  matrix.drawFastHLine(3, 1, 2, c_tree);
  matrix.drawFastHLine(2, 2, 4, c_tree);
  matrix.drawFastHLine(2, 3, 4, c_tree);
  matrix.drawFastHLine(1, 4, 6, c_tree);
  matrix.drawFastHLine(1, 5, 6, c_tree);
  matrix.drawFastHLine(0, 6, 8, c_tree);
  // Trunk
  matrix.drawFastHLine(3, 7, 2, matrix.Color(180, 130, 0));
  // Decorations
  matrix.drawPixel(3, 3, c_dec);
  matrix.drawPixel(5, 4, c_dec);
  matrix.drawPixel(2, 5, c_dec);
}

void drawSkull(uint32_t c) {
  matrix.drawFastHLine(1, 0, 6, c);
  matrix.drawFastHLine(1, 1, 6, c);
  matrix.drawFastVLine(0, 1, 4, c);
  matrix.drawFastVLine(7, 1, 4, c);
  matrix.drawFastHLine(3, 2, 2, c);
  matrix.drawFastHLine(2, 3, 4, c);
  matrix.drawFastHLine(1, 4, 6, c);
  matrix.drawFastHLine(1, 5, 6, c);
  matrix.drawPixel(2, 6, c);
  matrix.drawPixel(5, 6, c);
  matrix.drawFastHLine(2, 7, 4, c);
}

void drawHeart(uint32_t c) {
  matrix.drawFastHLine(1, 1, 2, c);
  matrix.drawFastHLine(4, 1, 2, c);
  matrix.drawFastHLine(0, 2, 7, c);
  matrix.drawFastHLine(0, 3, 7, c);
  matrix.drawFastHLine(1, 4, 5, c);
  matrix.drawFastHLine(2, 5, 3, c);
  matrix.drawPixel(3, 6, c); 
}

void drawMode(int mode_id, uint32_t c) {
   matrix.setBrightness(brightMax);
   if (mode == 0) {
      drawWelcome(vStep);
    } else if ((mode == 1) || (mode == 2)) {  // Big square and blinking one
      matrix.fillScreen(c);
    } else if ((mode == 3) || (mode == 4)) {  // Circle and blinking circle
      matrix.fillScreen(0);
      drawDot(c);
    } else if ((mode == 5) || (mode == 6)) {  // Heart and blinking heart
      matrix.fillScreen(0);
      drawHeart(c);
    } else if (mode == 7) { // Scull
      matrix.fillScreen(0);
      drawSkull(c);
    } else if (mode == 8) { // Space invader
      matrix.fillScreen(0);
      drawInvader(c);
    } else if (mode == 9) { // Tree
      matrix.fillScreen(0);
      drawChristmasTree(matrix.Color(50, 140, 50), c);
    }
    matrix.show(); // Sends the updated pixel colors to the hardware.
}
    
void loop() {
  if (checkModeButton(PIN_MODE_BTN)) {
    drawMode(mode, colors[colorIndex]);
    delay(100);
  }
  if (checkColorButton(PIN_COLOR_BTN)) {
    drawMode(mode, colors[colorIndex]);
    delay(100);
  }
  // Setup bright only on 0 mode
  if ((mode == 0) && checkBrightButton(PIN_BRIGHT_BTN)) {
    matrix.setBrightness(brightMax);
    delay(50);
  } else {
    // Update blinking effect
    if ((mode == 2) || (mode == 4) || (mode == 6)) {
      updateBrightEffect();
      delay(50);
    }
    if (mode == 0) {
      drawMode(mode, colors[colorIndex]);
      delay(100);
      vStep += vMove;
    }
  }
  // To avoid duplicate operations
  if (ticks < 100) {
    ticks += 1;
    delay(25);
  }
}

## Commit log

2018-01-23 Added sketch
    [BikePixel sketch.fzz]
2018-01-27 Improved protoboard schema, added PCB and production files. Written more documentation
    [BikeBixel box v2 copia.FCStd, BikePixel sketch.fzz, case.FCStd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]
2018-01-27 Added case image do readme
2018-01-28 Finished case design
    [BikeBixel box v2 copia.FCStd, case bottom plexi 1mm black.dxf, case bottom.FCStd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]
2018-01-30 Set PIN numbers according to schema
2018-06-18 New PCB with proper resistors
    [sketch pcb.fzz]
2018-07-01 Updated PCB design
    [sketch pcb.fzz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]
2018-08-15 Improved protoboard. Added extra documentation
    [sketch protoboard.fzz]
2018-09-03 New case design
    [case arduino nano.FCStd, case base.FCStd, case bottom.FCStd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]
2018-09-09 Updated case and documentation
    [case bottom plexi 1mm black.dxf, case middle plexi 6mm black.dxf, case top plexi 1mm transparent.dxf]
2018-09-30 Improved documentation added optional middle part for the case
    [case middle optional.FCStd, sketch pcb.fzz, sketch protoboard.fzz]
2018-09-30 Added heart icon and the capability to change the matrix birgthness by pressiong one of the buttons
2019-09-21 First 3D printed case. Added Lisences
    [case_print.scad, case_print.stl]
2020-11-06 Separate between rear and front models
    [bike pixel front copia.scad, bike pixel front.FCStd, bike pixel front.scad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]
2020-11-10 Updated pcb design with battery connection and on button. Added basic battery checking into code. Added 3D printed basic case model
    [case arduino nano.FCStd, case base.FCStd, case bottom.FCStd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]
2021-01-24 Added new pcb design including power connections
    [bikepixel rear sketch pcb.fzz, bikepixel rear sketch protoboard.fzz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]
2021-06-15 New rear PCB version. Added new PCB case
    [bikepixel rear sketch pcb.fzz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]
2021-06-15 Updated design related files and documentation
    [case arduino nano.FCStd, case base.FCStd, case bottom.FCStd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]
2021-06-15 Added last BP front design (deprecated)
    [bike pixel front copia.scad, bike pixel front.FCStd, bike pixel front.scad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]
2021-06-15 Update all
    [bike pixel front copia.scad, bike pixel front.FCStd, bike pixel front.scad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]
2021-11-14 Added files for bike pixel rear with battery support and 3d printed case
    [bikepixel rear sketch pcb_contour.gm1, bikepixel rear sketch pcb_copperBottom.gbl, bikepixel rear sketch pcb_copperTop.gtl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]
2021-11-29 Added PCB design. Improved documentation
    [bikepixel rear.kicad_pcb, bikepixel rear.sch, case_bikepixels_rear.FCStd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]
2021-12-01 Added Bike Pixel L conection schema
    [bikepixel-L-connection-breadboard.fzz]
2021-12-01 Front drafts
    [bike pixel front.FCStd, bike_pixel_front.stl]

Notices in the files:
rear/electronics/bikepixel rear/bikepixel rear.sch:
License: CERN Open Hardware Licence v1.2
